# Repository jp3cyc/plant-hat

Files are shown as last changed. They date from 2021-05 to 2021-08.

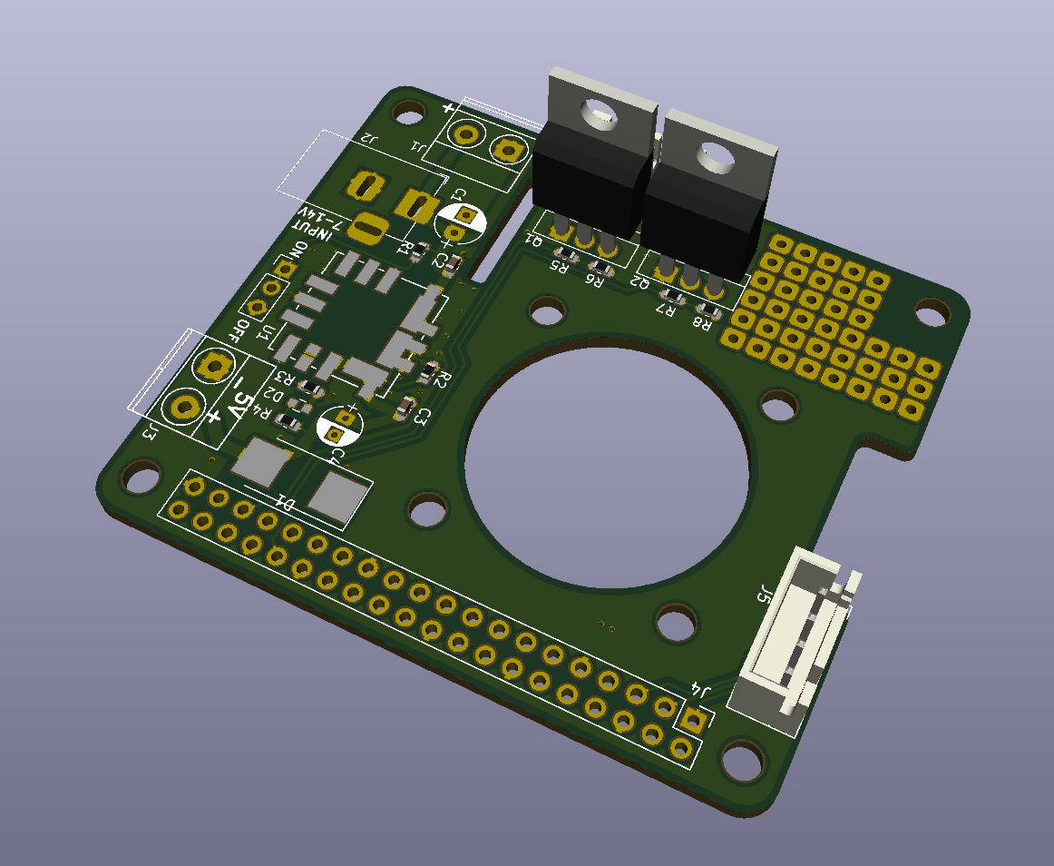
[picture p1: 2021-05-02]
kurinuki.PNG

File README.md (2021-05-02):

# plant-hat
ラズパイで植物の水やりをするための基板

# 機能
  - 12V入力対応（ラズパイ用USB電源不要）
  - 12VモータPWM駆動回路搭載
  - I2C用コネクタ搭載
  - ユニバーサル基板エリアあり
  - 3cm角ファン搭載可能

# 使い方
## 電源ON
  DCジャックに12V電源を差し込み，スイッチをONにするとラズパイが起動します．（Rev1基板ではON-OFFの印刷が逆転しています）
  
## GPIO操作
  - J7コネクタはGPIO 35，J6コネクタは32番に接続されています．
  - GPIO35番をONにしたいときは，GPIO35の出力をHにしてください．
  - GPIO35，GPIO32はPWM出力に対応しているので，PWM出力が可能です（未検証）
  - ラズパイのGPIOを操作できればソフトウェアは何でも使えます（例：C，Python，Node-redなど）

## 利用上の注意
Raspberry Piの時計のタイマーは符号付き32bit intで実装されている都合上，2038年1月19日12時14分7秒(JST)を超えると，1901年にタイムスリップします．
そのため，2038年1月19日12時14分7秒をまたぐ水やりを行うと，プログラムの実装によっては水が出続ける可能性があります．
ご利用時はご注意ください．

参考文献
https://ja.wikipedia.org/wiki/2038%E5%B9%B4%E5%95%8F%E9%A1%8C

https://www.youtube.com/watch?v=WLyIPslm_rw

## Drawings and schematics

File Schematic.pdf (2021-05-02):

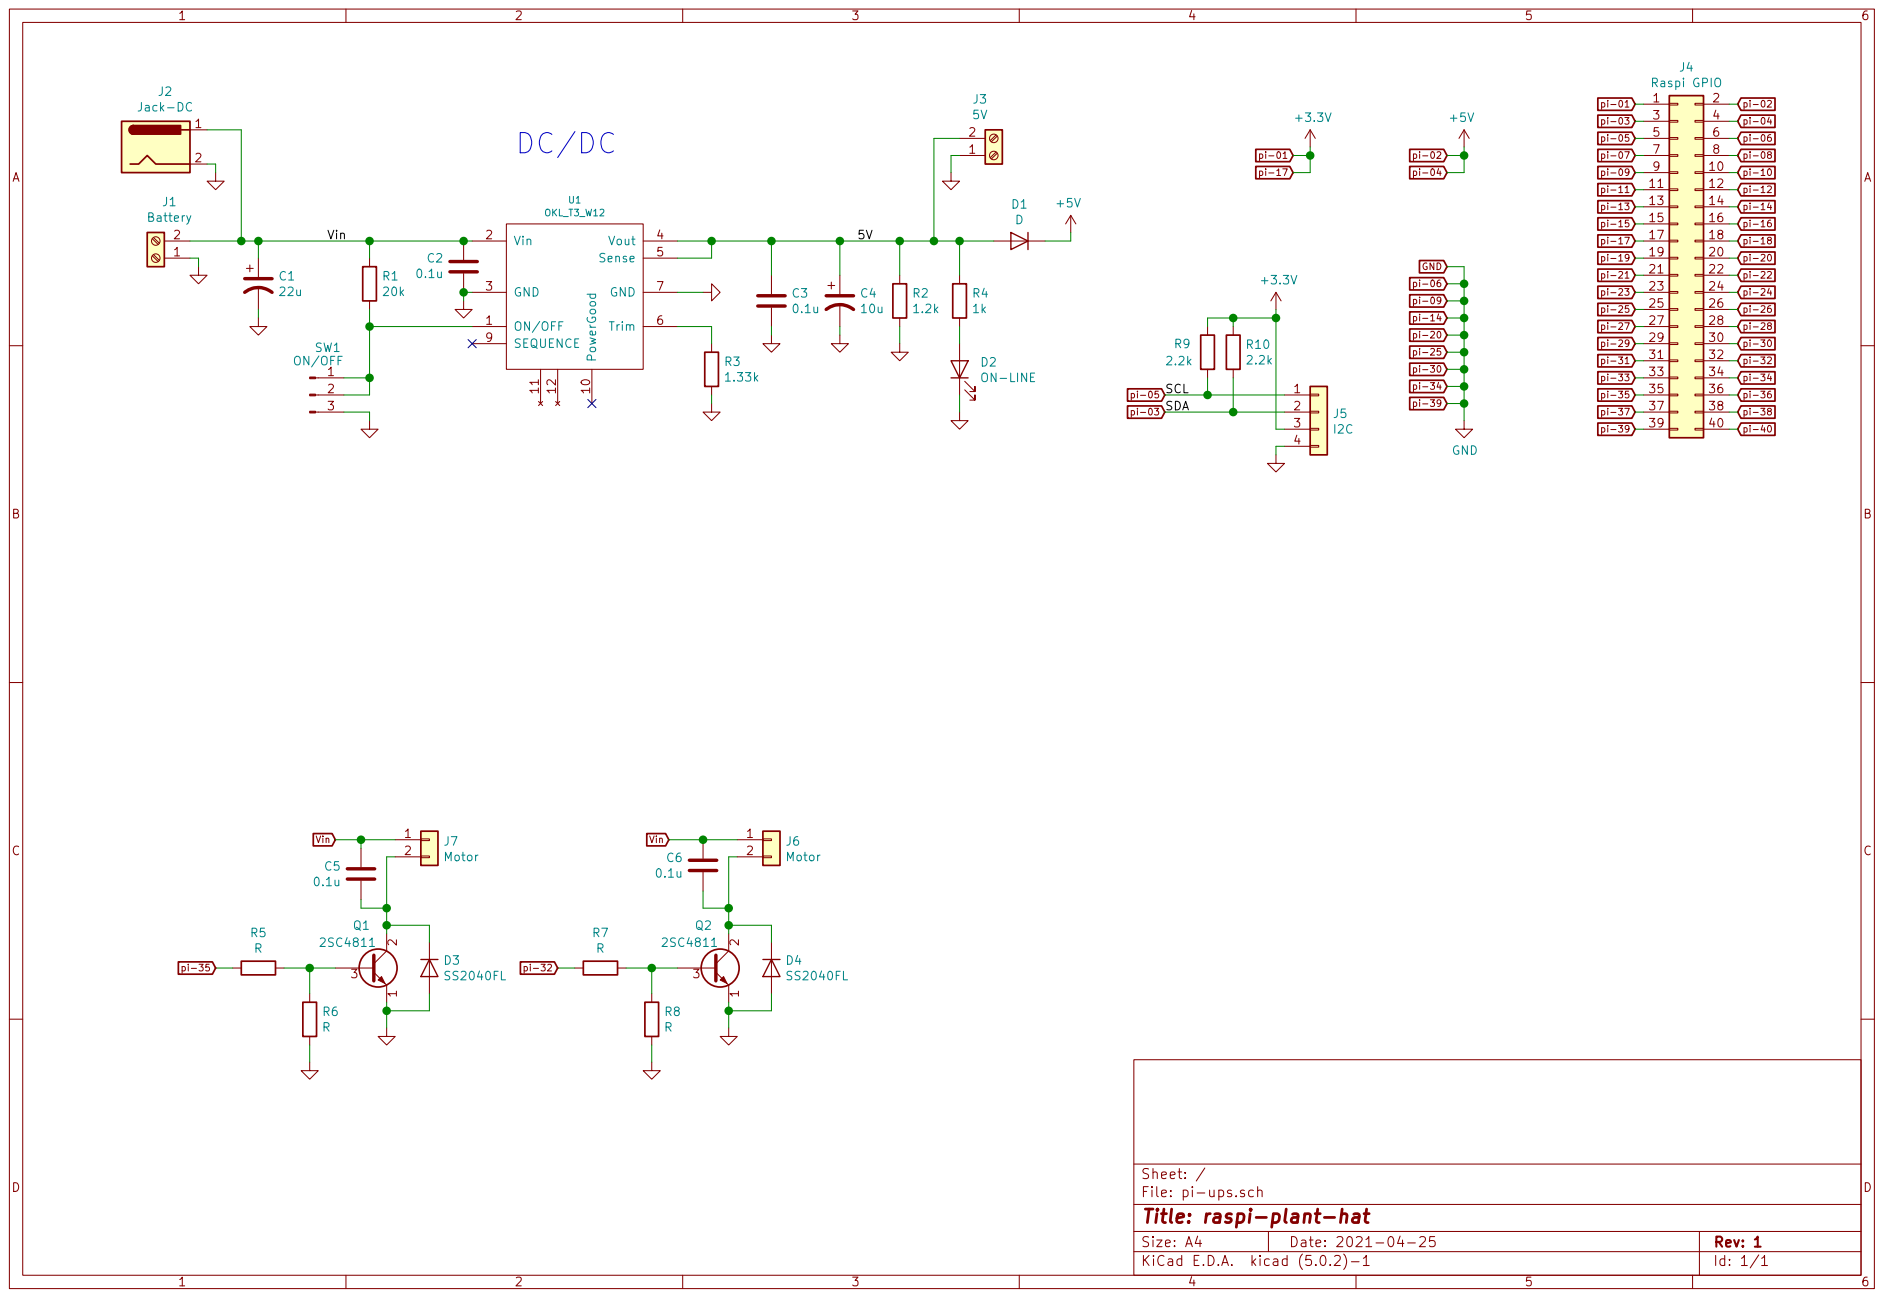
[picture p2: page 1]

File: pi-ups.sch Sheet: /
Id: 1/1 Title: raspi-plant-hat

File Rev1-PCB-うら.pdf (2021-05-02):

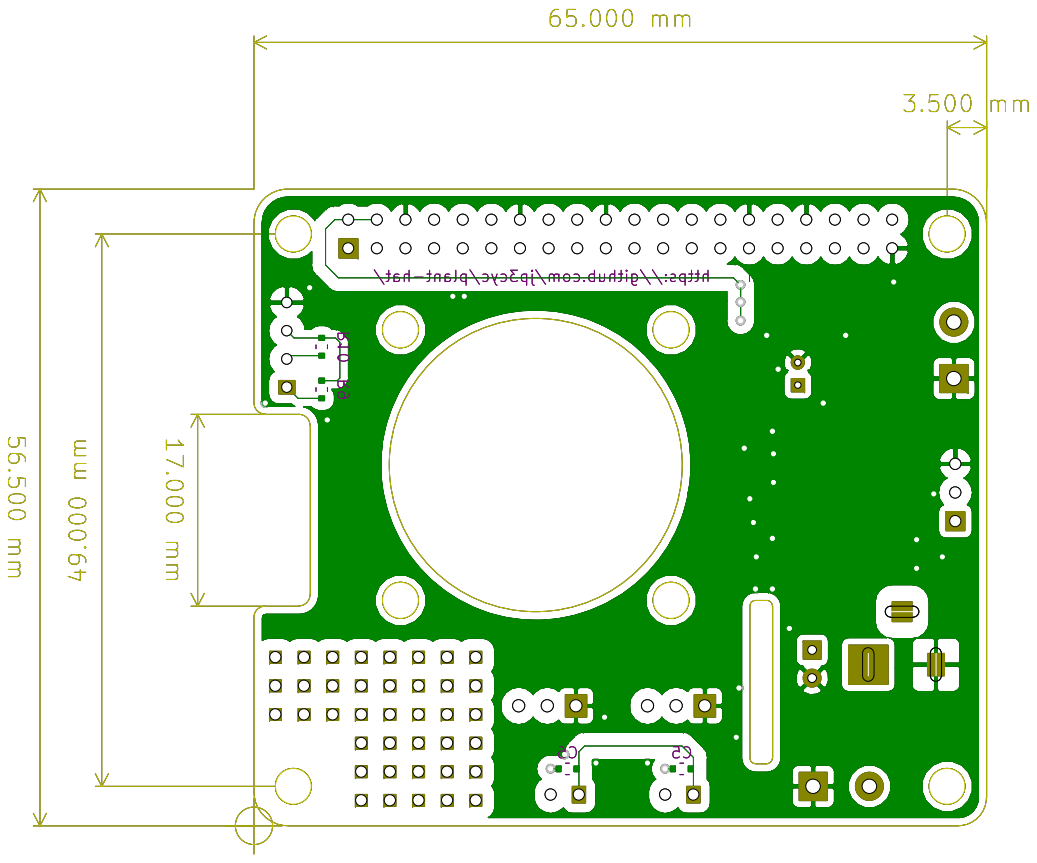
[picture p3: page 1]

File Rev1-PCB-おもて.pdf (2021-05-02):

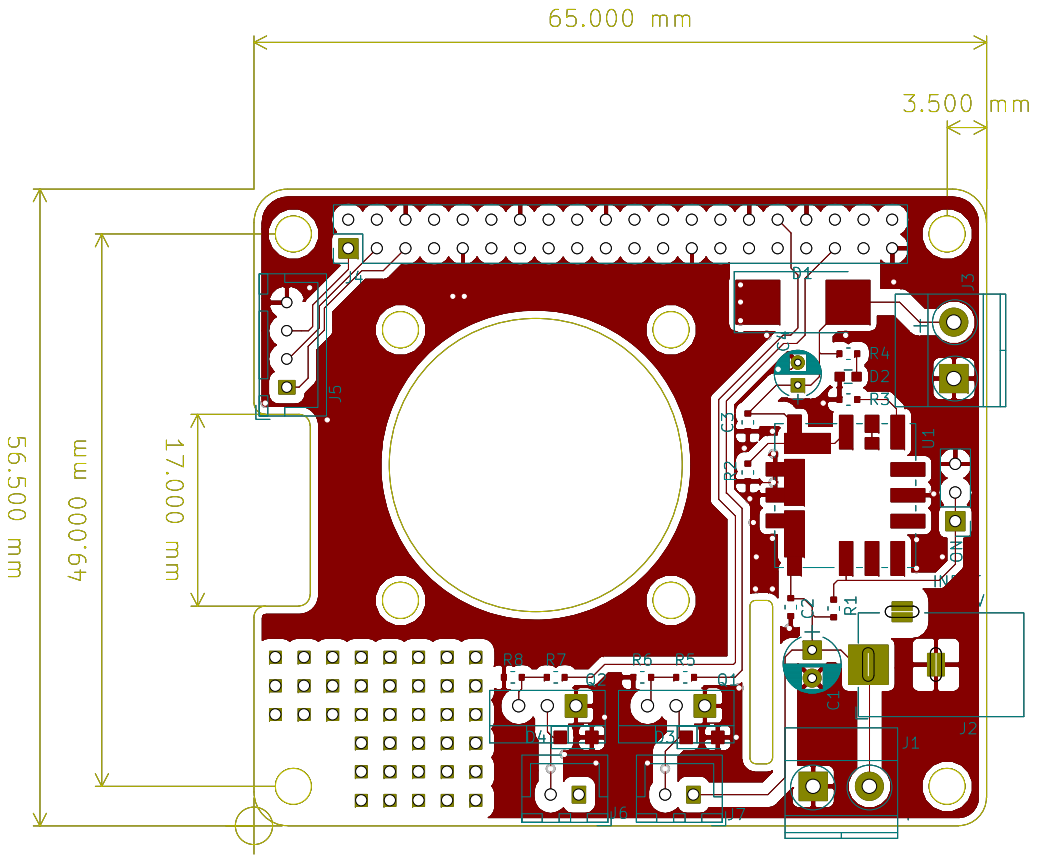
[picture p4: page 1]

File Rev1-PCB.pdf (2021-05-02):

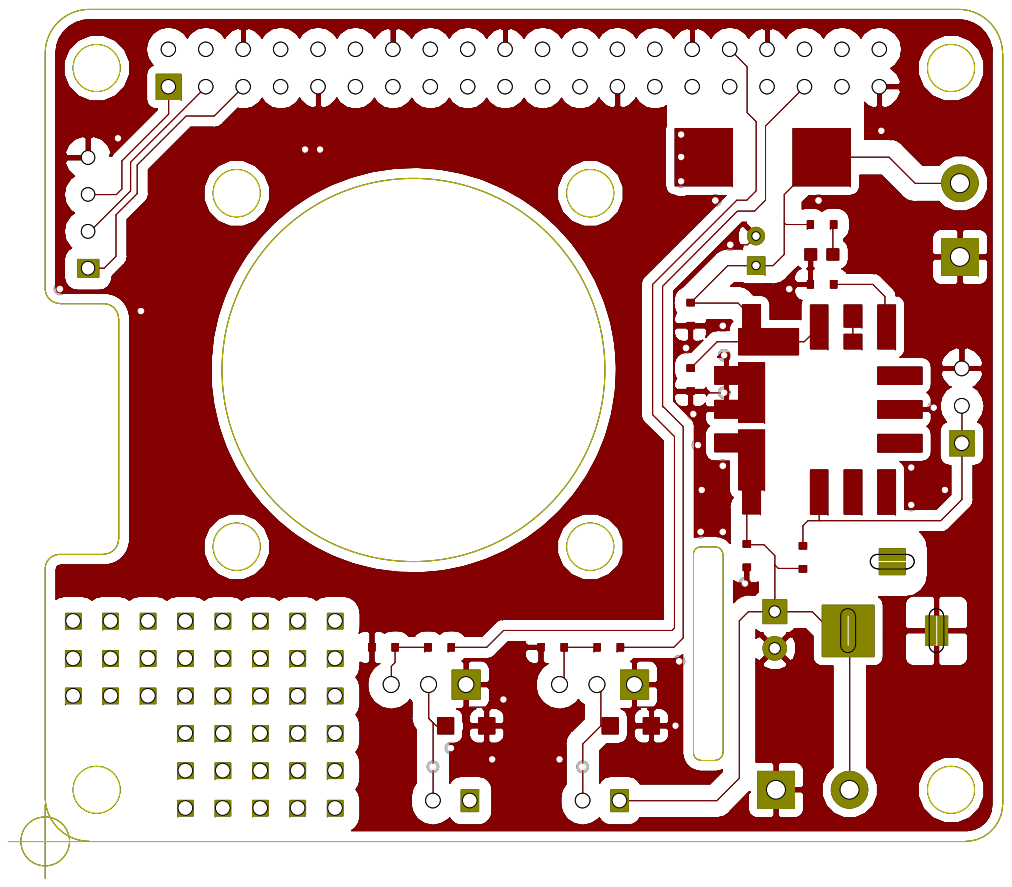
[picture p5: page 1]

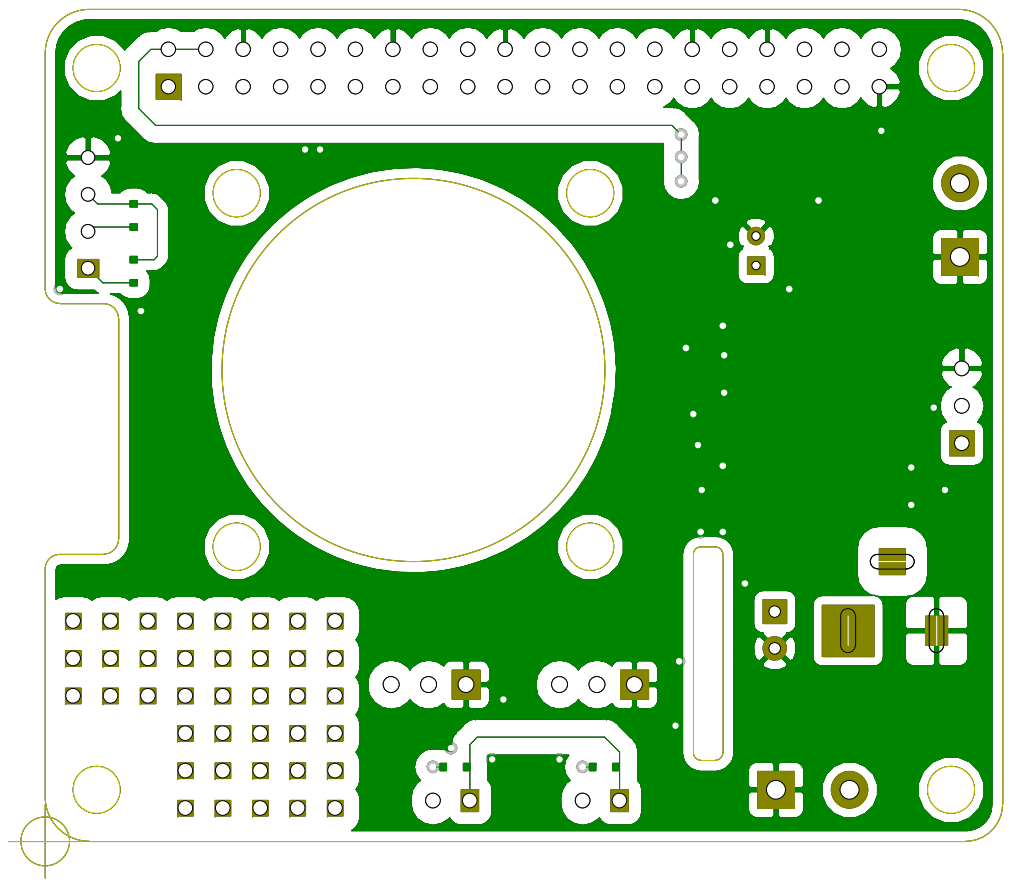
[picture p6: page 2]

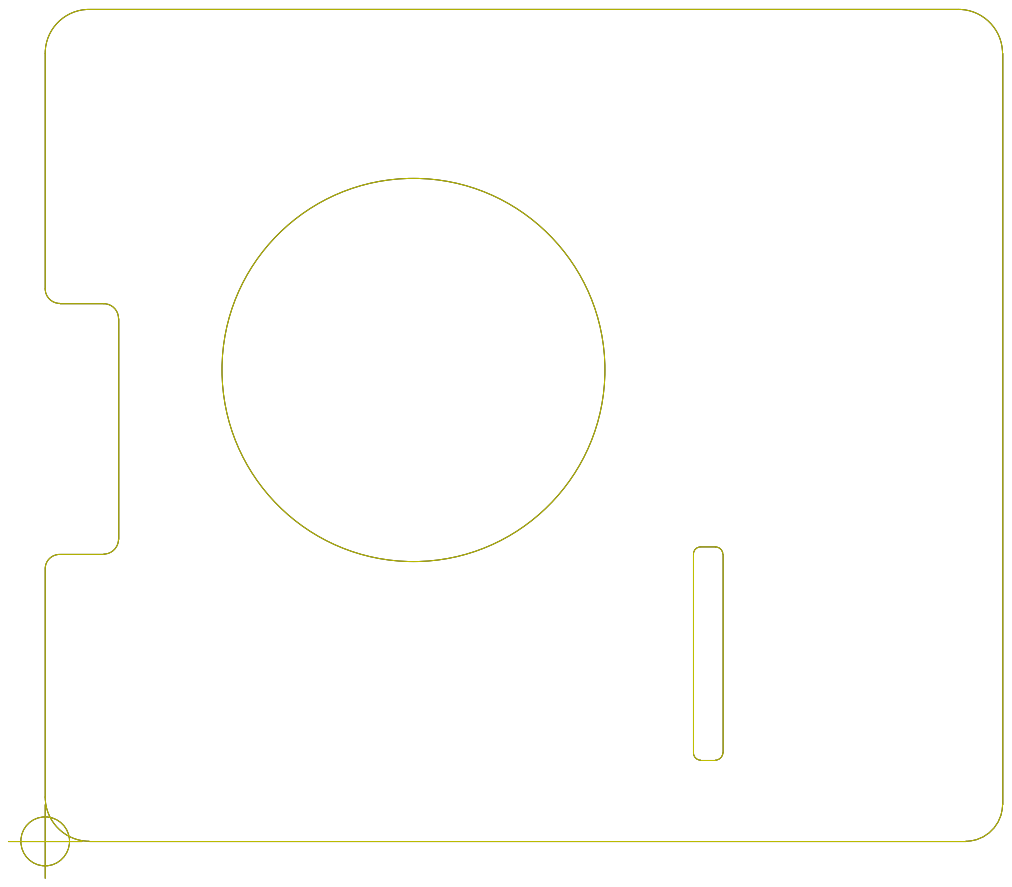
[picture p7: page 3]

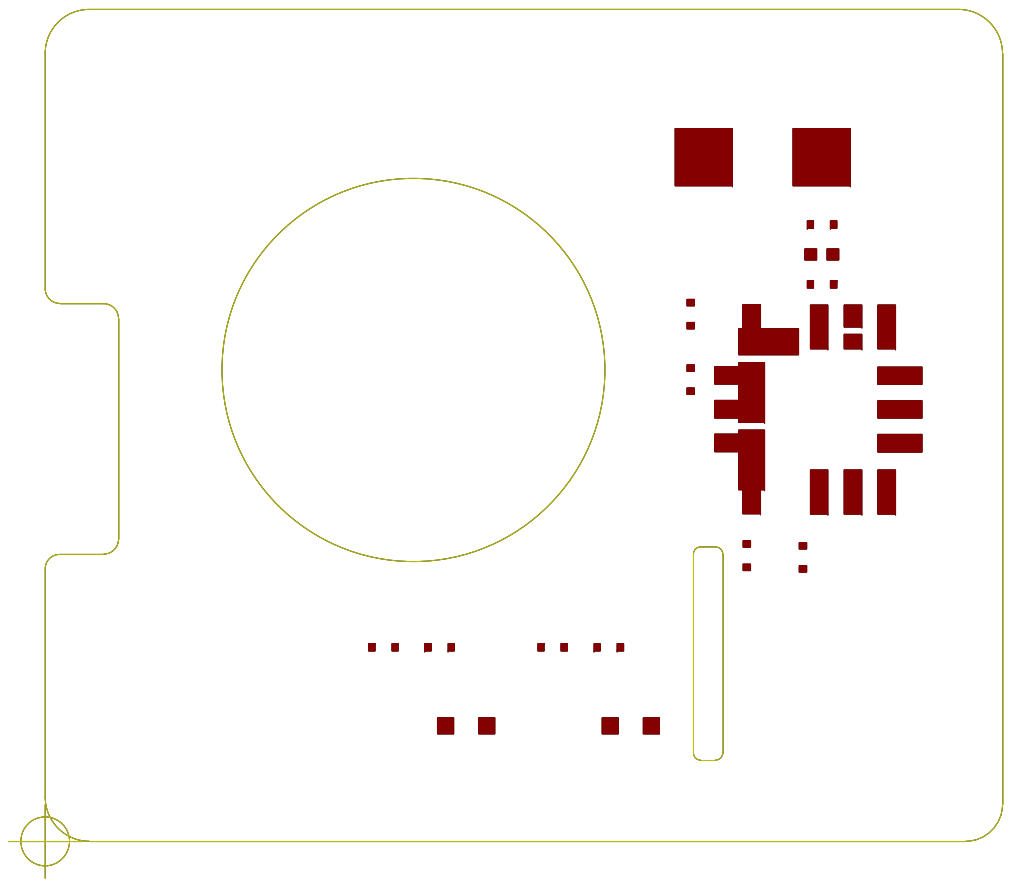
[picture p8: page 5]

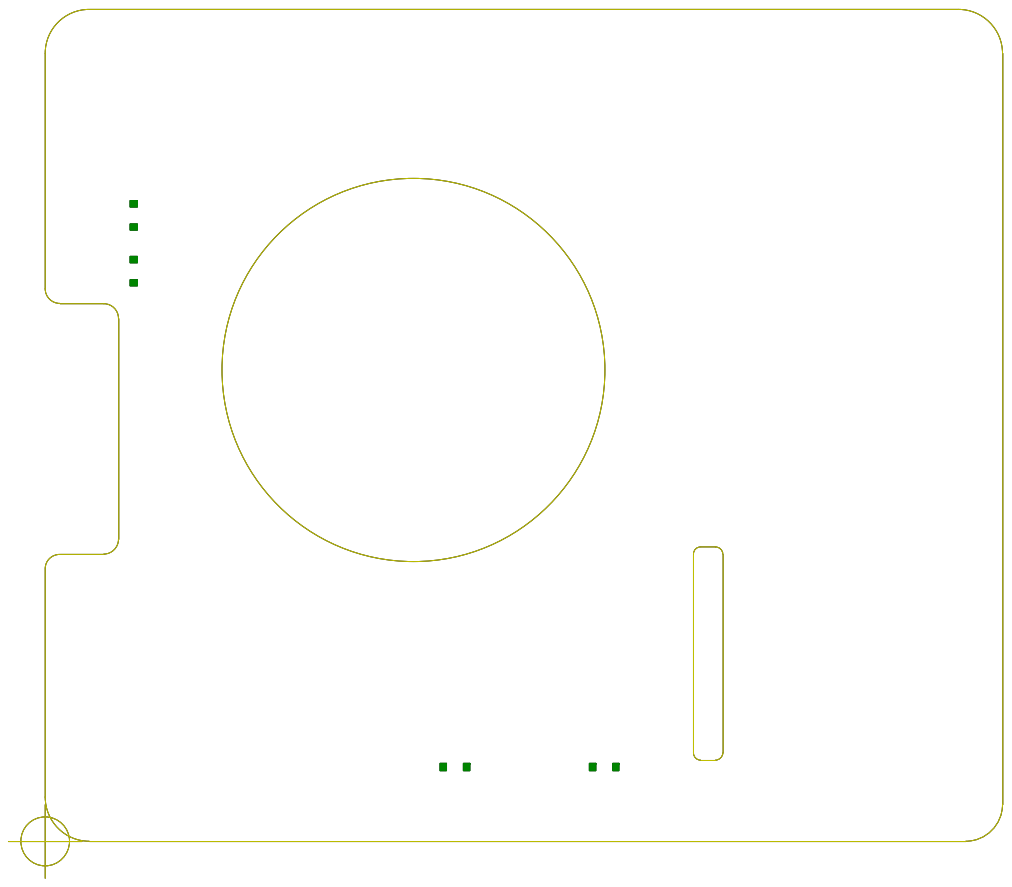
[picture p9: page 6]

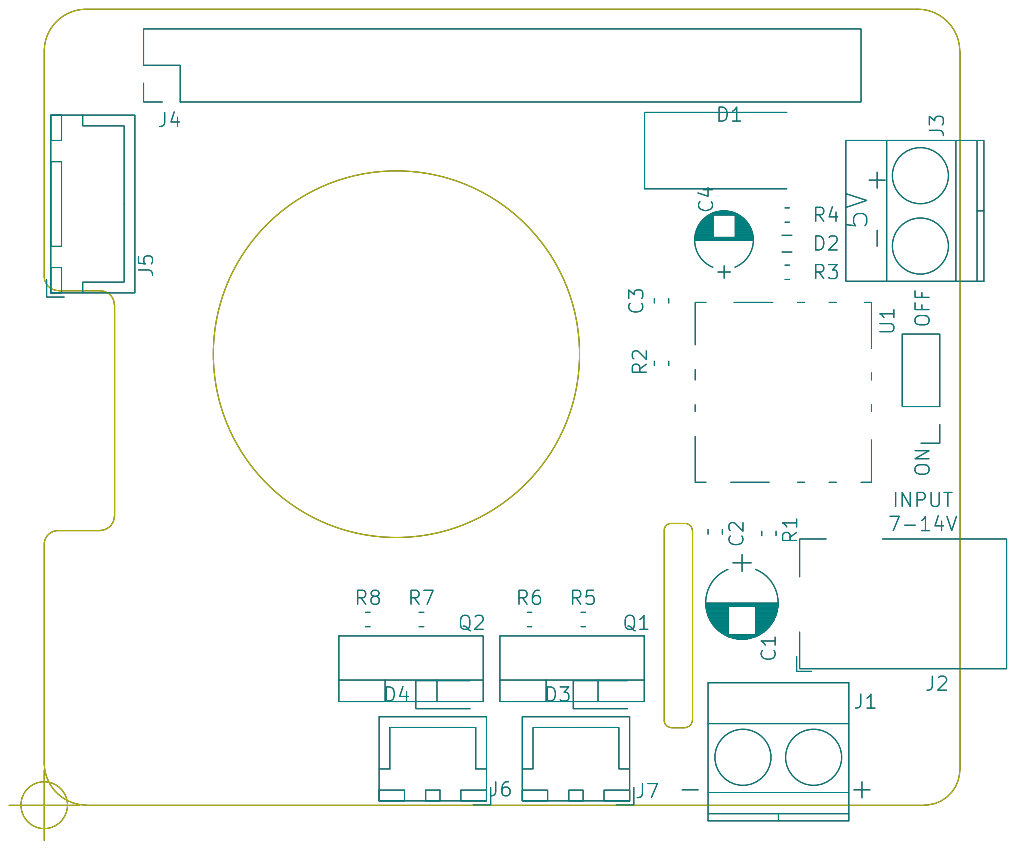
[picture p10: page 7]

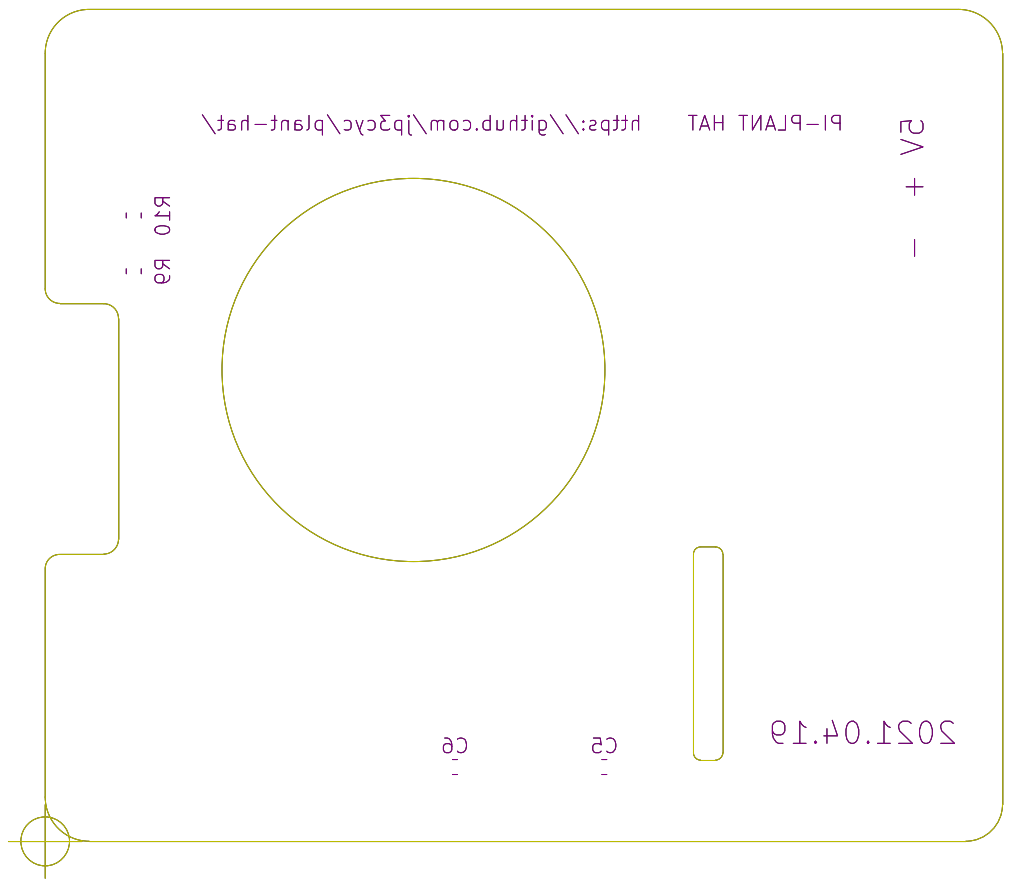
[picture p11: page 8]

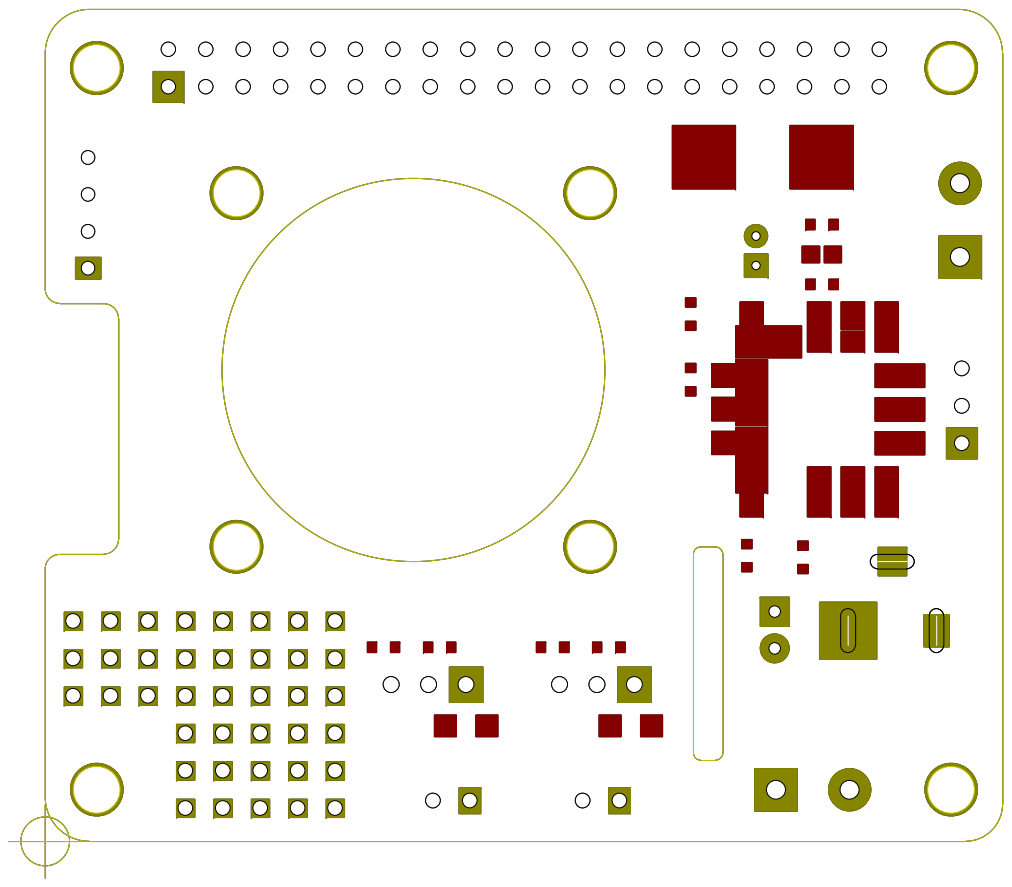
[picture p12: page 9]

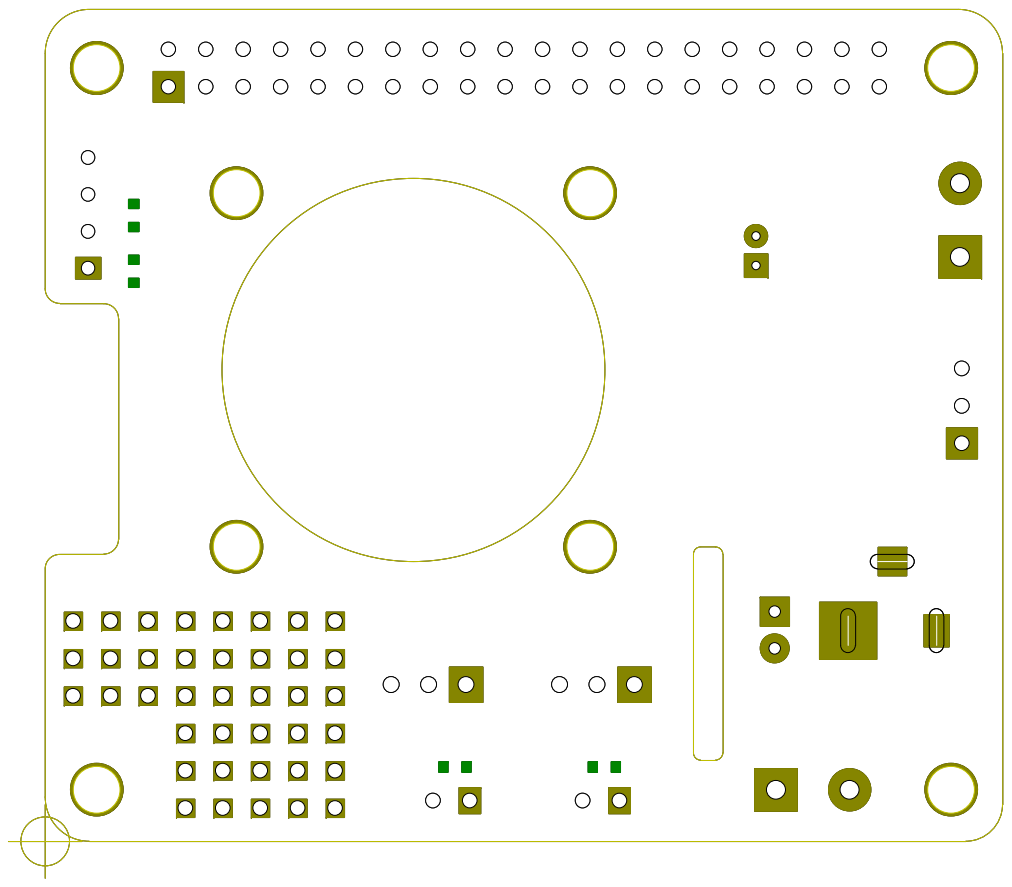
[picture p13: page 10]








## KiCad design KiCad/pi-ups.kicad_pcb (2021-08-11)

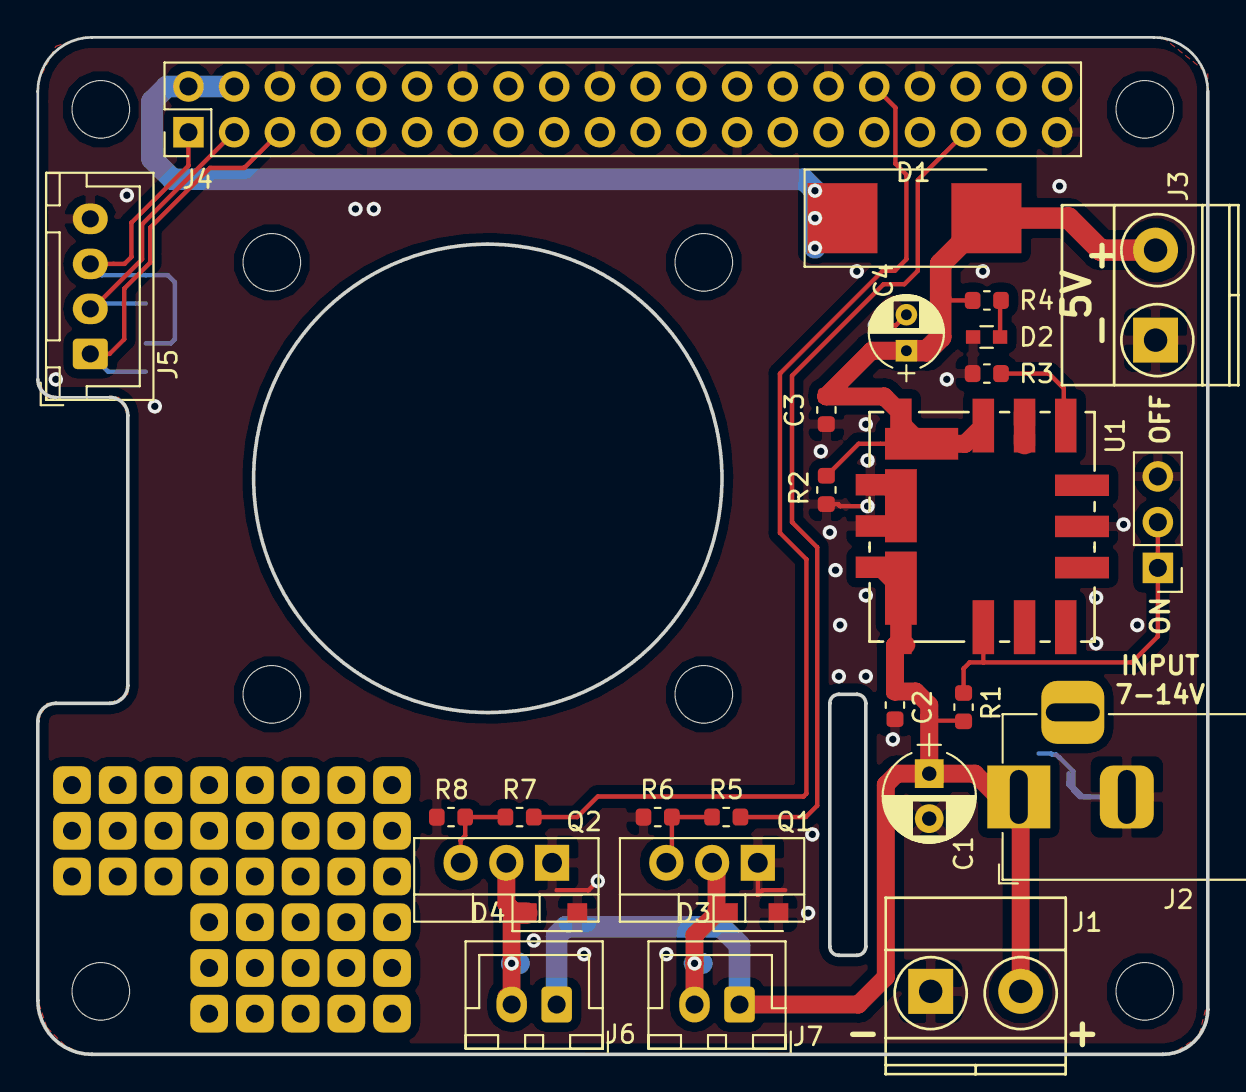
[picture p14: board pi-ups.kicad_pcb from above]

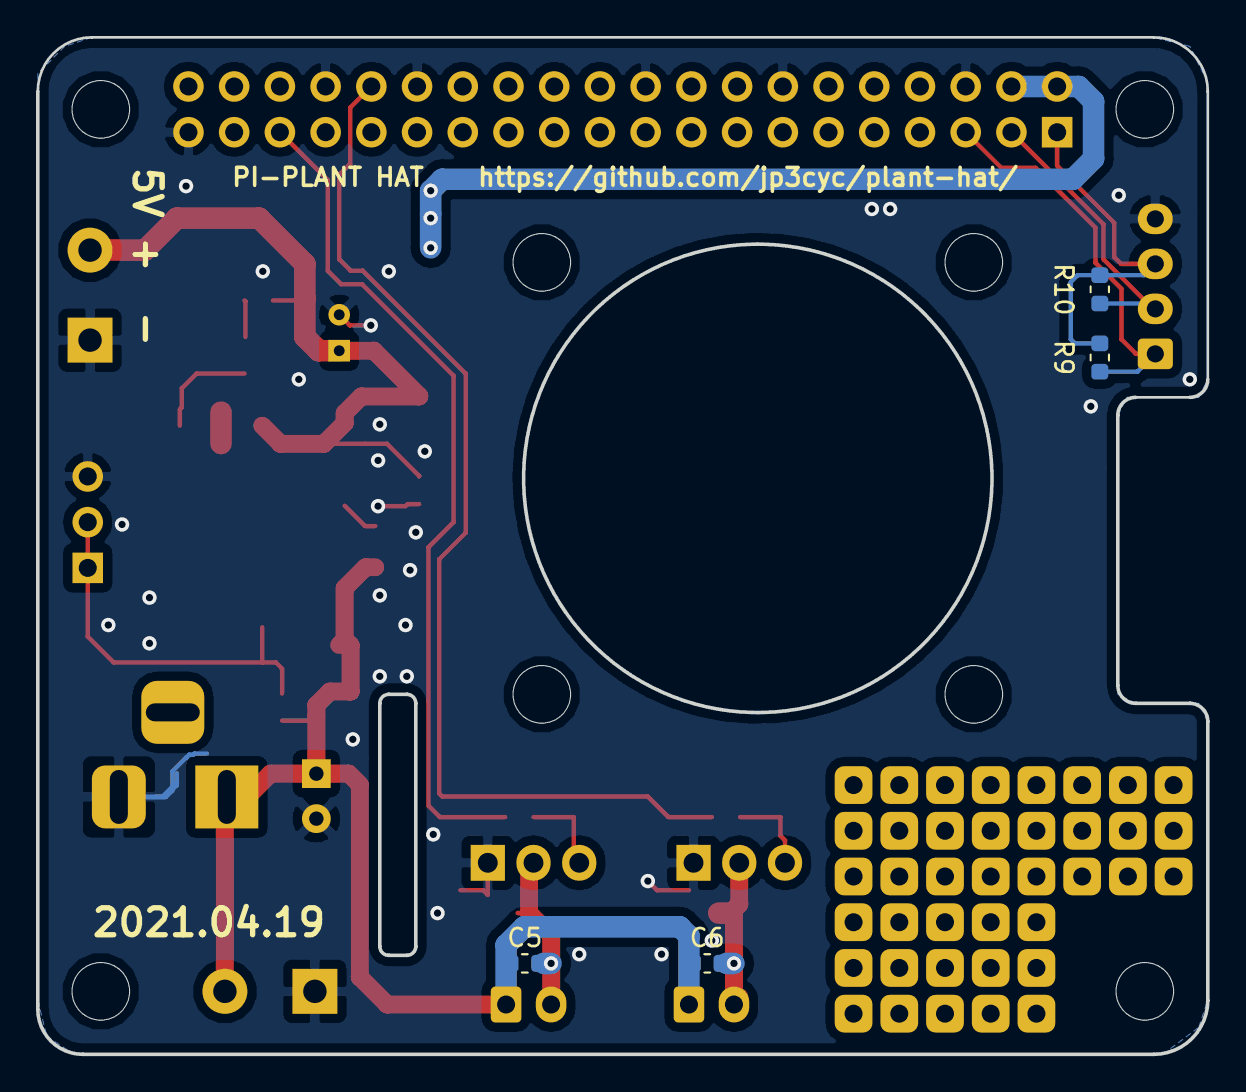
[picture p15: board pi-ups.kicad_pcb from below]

Board: 2 copper layers, 65.0 x 56.5 mm, 31 parts (4 on the bottom side), 16 nets.

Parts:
C1: 22u; CP_Radial_D5.0mm_P2.50mm
C2, C3, C5, C6: 0.1u; C_0603_1608Metric
C4: 10u; CP_Radial_D4.0mm_P2.00mm
D1: D; D_3220
D2: ON-LINE; C_0603
D3, D4: SS2040FL; D_SOD-123F
J1: Battery; TerminalBlock_Pheonix_MKDS1.5-2pol
J2: Jack-DC; BarrelJack_Horizontal
J3: 5V; TerminalBlock_Pheonix_MKDS1.5-2pol
J4: Raspi GPIO; Pin_Header_Straight_2x20_Pitch2.54mm
J5: I2C; JST_XH_B04B-XH-A_1x04_P2.50mm_Vertical
J6, J7: Motor; JST_XH_B02B-XH-A_1x02_P2.50mm_Vertical
Q1, Q2: 2SC4811; TO-220-3_Vertical
R1: 20k; R_0603_1608Metric
R2: 1.2k; R_0603_1608Metric
R3: 1.33k; R_0603_1608Metric
R4: 1k; R_0603_1608Metric
R5, R6, R7, R8: R; R_0603_1608Metric
R9, R10: 2.2k; R_0603_1608Metric
SW1: ON/OFF; Pin_Header_Straight_1x03_Pitch2.54mm
U1: OKL_T3_W12

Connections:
/5V: C3.1, C4.1, D1.2, J3.2, R2.1, R4.1, U1.4, U1.5
GND: C1.2, C2.1, C3.2, C4.2, D2.1, D3.2, D4.2, J1.1, J2.2, J3.1, J4.6, J4.9, J4.14, J4.20, J4.25, J4.30, J4.34, J4.39, J5.4, Q1.1, Q2.1, R2.2, R3.2, R6.2, R8.2, SW1.3, U1.3, U1.7
unnamed: C5.2, D3.1, J7.2, Q1.2
unnamed: C6.2, D4.1, J6.2, Q2.2
unnamed: D2.2, R4.2
unnamed: Q1.3, R5.1, R6.1
unnamed: Q2.3, R7.1, R8.1
unnamed: R1.2, SW1.1, SW1.2, U1.1
unnamed: R3.1, U1.6
Vin: C1.1, C2.2, C5.1, C6.1, J1.2, J2.1, J6.1, J7.1, R1.1, U1.2
pi-01: J4.1, J4.17, J5.3, R9.1, R10.1
pi-02: D1.1, J4.2, J4.4
pi-03: J4.3, J5.2, R10.2
pi-05: J4.5, J5.1, R9.2
pi-32: J4.32, R7.2
pi-35: J4.35, R5.2

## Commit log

2021-05-02 Init commit
    [pi-ups-B.Cu.gbr, pi-ups-B.Mask.gbr, pi-ups-B.Paste.gbr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]
2021-05-02 使い方を追加
2021-05-02 参考文献をついか
2021-08-11 organized data
    [pi-ups-B.Cu.gbr, pi-ups-B.Mask.gbr, pi-ups-B.Paste.gbr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]
